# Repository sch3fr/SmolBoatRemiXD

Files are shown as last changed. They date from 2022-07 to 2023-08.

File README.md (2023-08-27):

# SmolBoatRemiXD
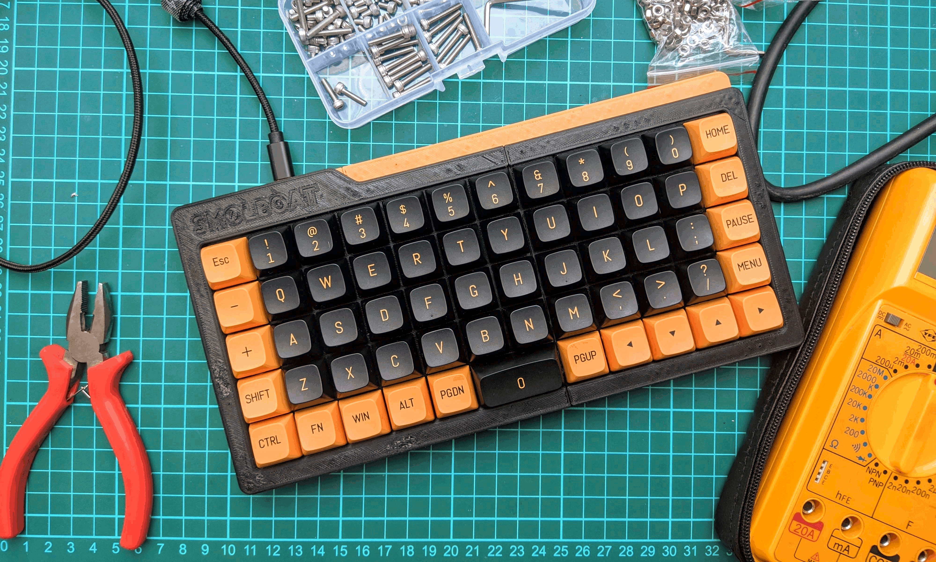
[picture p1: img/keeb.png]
smolboatremixd

SmolBoat is a custom 3D printed mechanical keyboard designed by [Druz320 on Thingiverse](https://www.thingiverse.com/thing:3289175).
While I really liked the design, there were some tweaks that I wanted to make, and I also needed smaller models, so I could print it
on my smaller 3D printer. Please note that this repo is focused only on the JJ50 clone.
## Changes compared to the original
- Changed the cutout to fit the SparkFun Pro Micro
- Added a hole for controller brace
- Added cherry stabiliser for 2U spacebar
- Added smaller cut files to print on my 3D printer
## Cuts
There are 4 smaller files, two for bottom and 2 for the top piece. The pieces have holes in them for pegs, of which you 
will need 4 of them. The pegs help with rugidity of the whole thing. I recommend glueing the pieces together. As I 
didn't have any glue suitable for PLA, I used a 3D pen to "weld" the pieces together, which is also a valid option, 
however make sure to sand down the top piece afterwards, or the switches may not sit flush.
## Wiring
This is a standard hand wired keyboards. The rows are connected with diodes, the columns are joined together with wire.<br>
| Rows | Columns |
|---|---|
|<table> <tr><th>Row number</th><th>Pin number</th></tr><tr><td>0</td><td>D3</td></tr><tr><td>1</td><td>D2</td></tr><tr><td>2</td><td>D1</td></tr><tr><td>3</td><td>D0</td></tr><tr><td>4</td><td>D4</td></tr></table>| <table> <tr><th>Column number</th><th>Pin number</th></tr><tr><td>0</td><td>B6</td></tr><tr><td>1</td><td>B2</td></tr><tr><td>2</td><td>B3</td></tr><tr><td>3</td><td>B1</td></tr><tr><td>4</td><td>F7</td></tr><tr><td>5</td><td>F6</td></tr><tr><td>6</td><td>F5</td></tr><tr><td>7</td><td>F4</td></tr><tr><td>8</td><td>B5</td></tr><tr><td>9</td><td>B4</td></tr><tr><td>10</td><td>E6</td></tr><tr><td>11</td><td>D7</td></tr> </table>|
### Wiring diagram
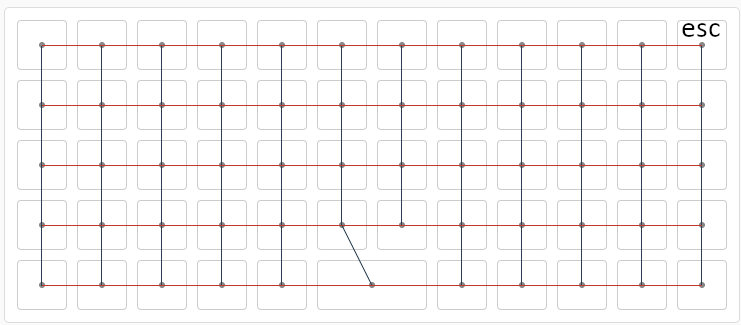
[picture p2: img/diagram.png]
Wiring diagram

## Firmware
~~The firmware is your standard .HEX file compiled in QMK. You can find my .HEX as well as the full source files on my 
Github page. I'd recommend you to write your own keymap, as I used mapping for Czech layout.~~

The firmware is compiled using Vial, meaning you can edit your keymap wiht nice UI without needing to rewrite and 
recompile it everytime you want to make some changes. It is still based on my czech keymap, meaning you probably want
to make your own
## Installation
1. Print all the pieces
1. Add switches
1. Wire according to the diagram, diodes between the rows, wire between columns
1. Connect to a computer, short RST and Ground pins
1. Flah smolboat_vial.hex

## Notes
I ended up not using the brace, since my awful wiring pushes the Pro Micro to its place.<br>
You might have to file the cherry stabs hole a bit for it to fit.<br>
~~I'd love to add Via support sometime in the future.~~ Vial is finally done ✅🥳

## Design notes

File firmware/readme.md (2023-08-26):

# smolboatremixd

smolboatremixd

*A short description of the keyboard/project*

* Keyboard Maintainer: [František](https://github.com/sch3fr)
* Hardware Supported: *Pro Micro, hand wiring*
* Hardware Availability: *[Original on thingiverse](https://www.thingiverse.com/thing:3289175), [My edited files](https://github.com/sch3fr/SmolBoatRemiXD/tree/main/STL)*

Make example for this keyboard (after setting up your build environment):

    make smolboatremixd:default

Flashing example for this keyboard:

    make smolboatremixd:default:flash

See the [build environment setup](https://docs.qmk.fm/#/getting_started_build_tools) and the [make instructions](https://docs.qmk.fm/#/getting_started_make_guide) for more information. Brand new to QMK? Start with our [Complete Newbs Guide](https://docs.qmk.fm/#/newbs).

## Bootloader

Enter the bootloader in 3 ways:

* **Bootmagic reset**: Hold down the key at (0,0) in the matrix (usually the top left key or Escape) and plug in the keyboard
* **Physical reset button**: You can add a microswitch to pins RST an one of the grounds to reset the board
* **Keycode in layout**: Press the key mapped to `RESET` if it is available

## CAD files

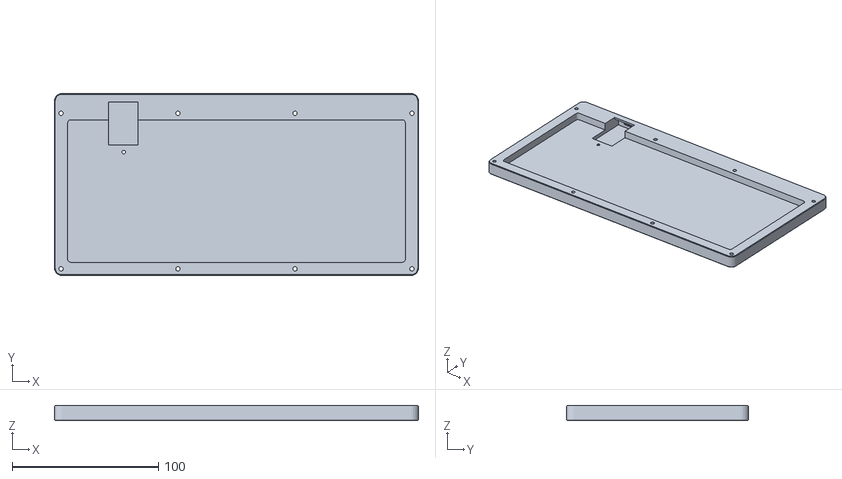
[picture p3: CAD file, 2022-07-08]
STL/BottomMix.stl
248.6 x 124.2 x 10.0

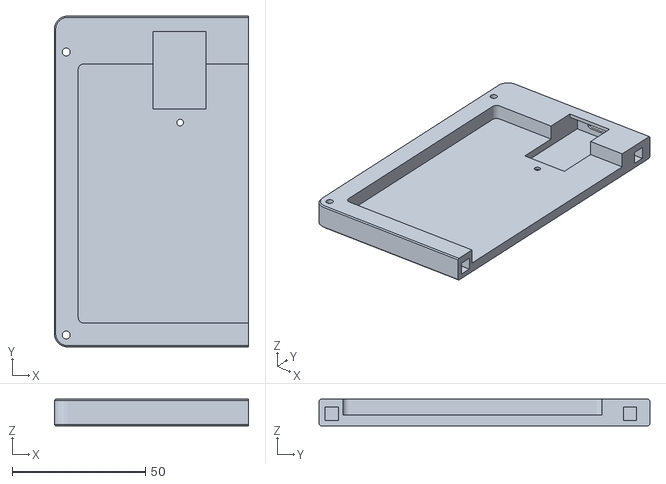
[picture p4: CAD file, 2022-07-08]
STL/Cuts/bottomLeft.stl
73.0 x 124.2 x 10.0

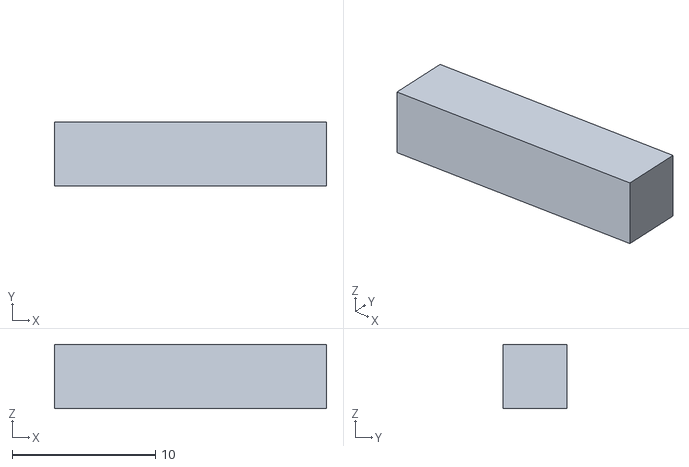
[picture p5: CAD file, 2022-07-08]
STL/Cuts/peg190_45_45.stl
19.0 x 4.50 x 4.50

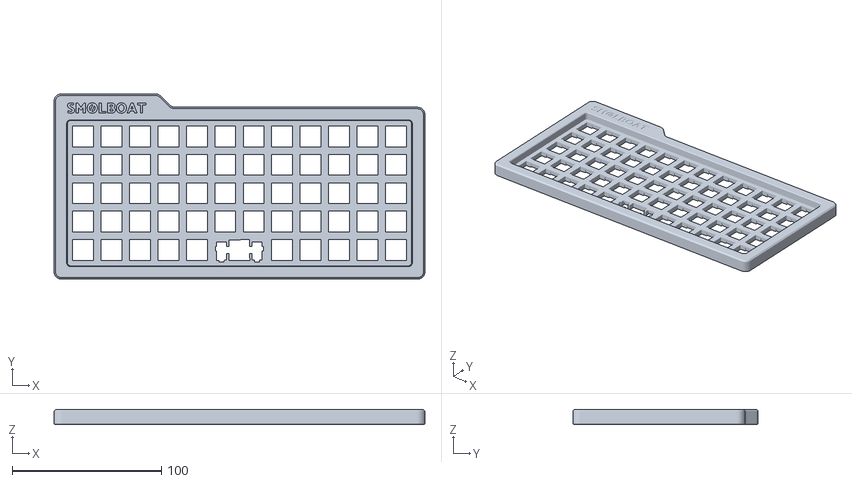
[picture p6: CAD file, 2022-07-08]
STL/TopMix.stl
248.6 x 124.2 x 10.0

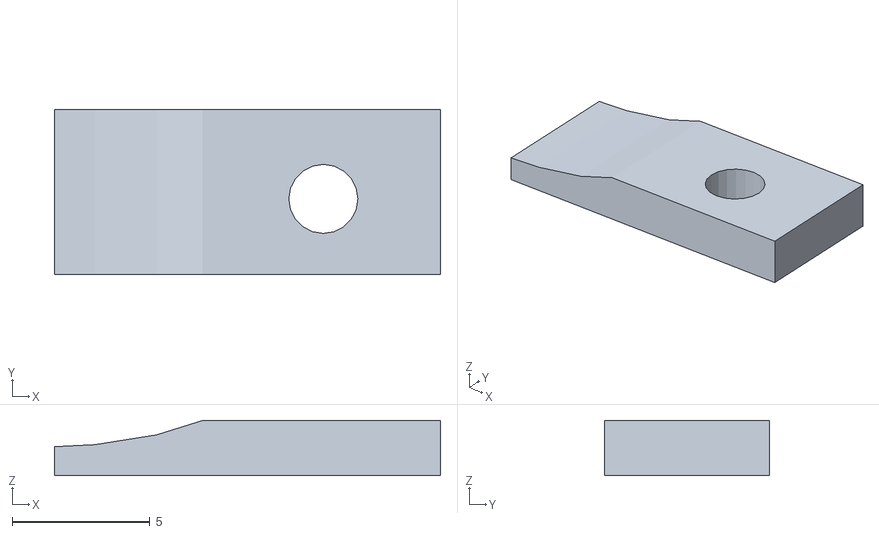
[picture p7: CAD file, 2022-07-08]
STL/ControllerBrace.stl
14.0 x 6.00 x 2.00

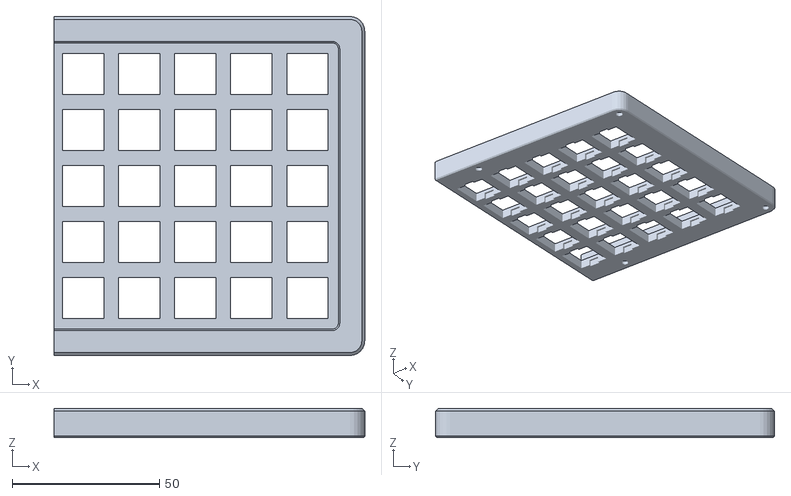
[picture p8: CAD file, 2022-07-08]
STL/Cuts/topRight.stl
105.6 x 115.2 x 10.0

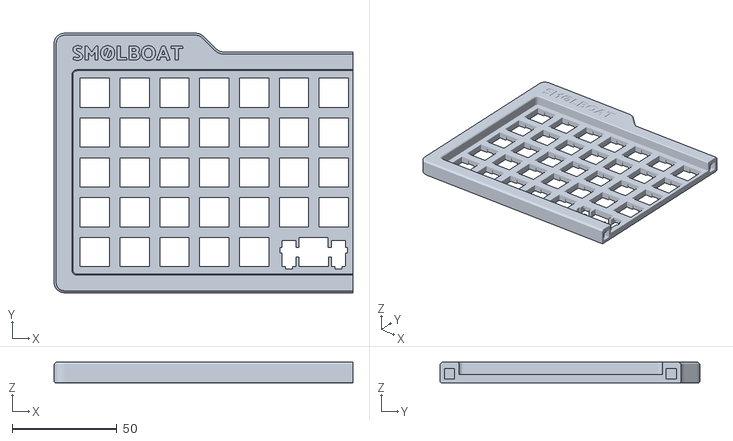
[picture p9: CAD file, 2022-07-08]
STL/Cuts/topLeft.stl
143.0 x 124.2 x 10.0

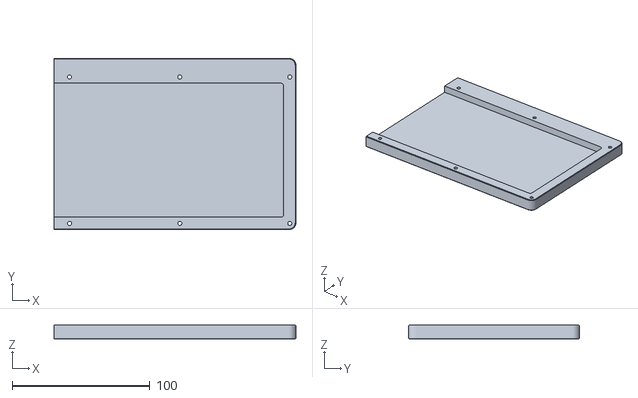
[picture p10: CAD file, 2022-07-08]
STL/Cuts/bottomRight.stl
175.6 x 124.2 x 10.0
